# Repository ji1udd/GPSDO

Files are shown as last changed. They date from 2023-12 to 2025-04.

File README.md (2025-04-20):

# GPSDO
## GPSDO for Hermes-Lite2 and a measuring instrument    
[Youtube video](https://youtu.be/AfCz8ohrafM)  

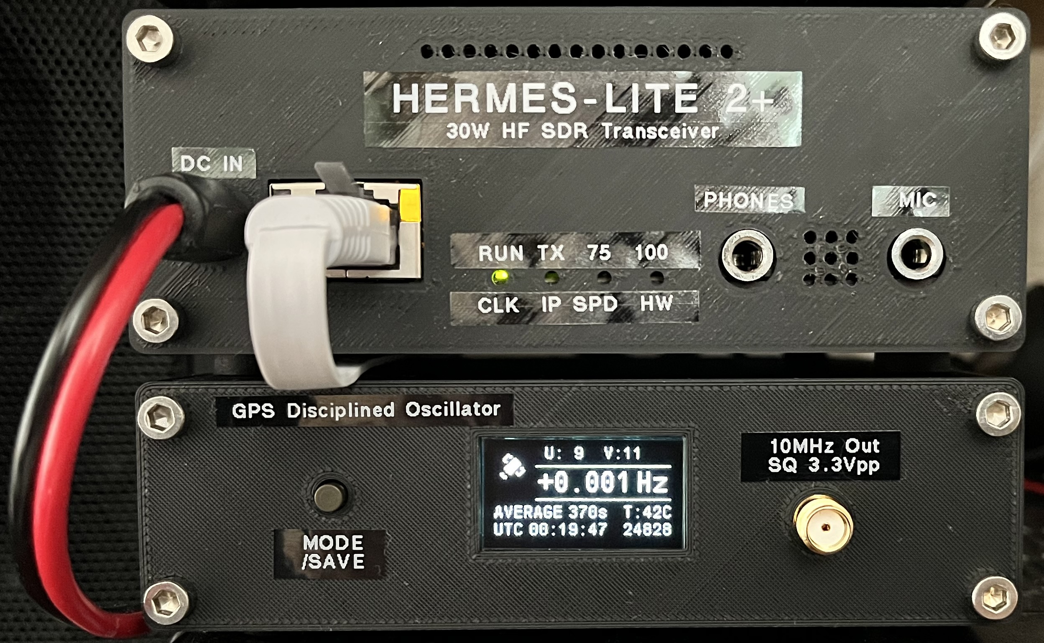
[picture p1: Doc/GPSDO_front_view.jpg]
  

GPSDO using a cheap used OCXO purchased from Aliexpress. It has 10MHz square wave output that can be directly connected to the external clock input of Hermes-Lite2 and 10MHz sine wave output (-10 dBm @ 50 ohm) that can be connected to a measuring instrument such as a spectrum analyzer.

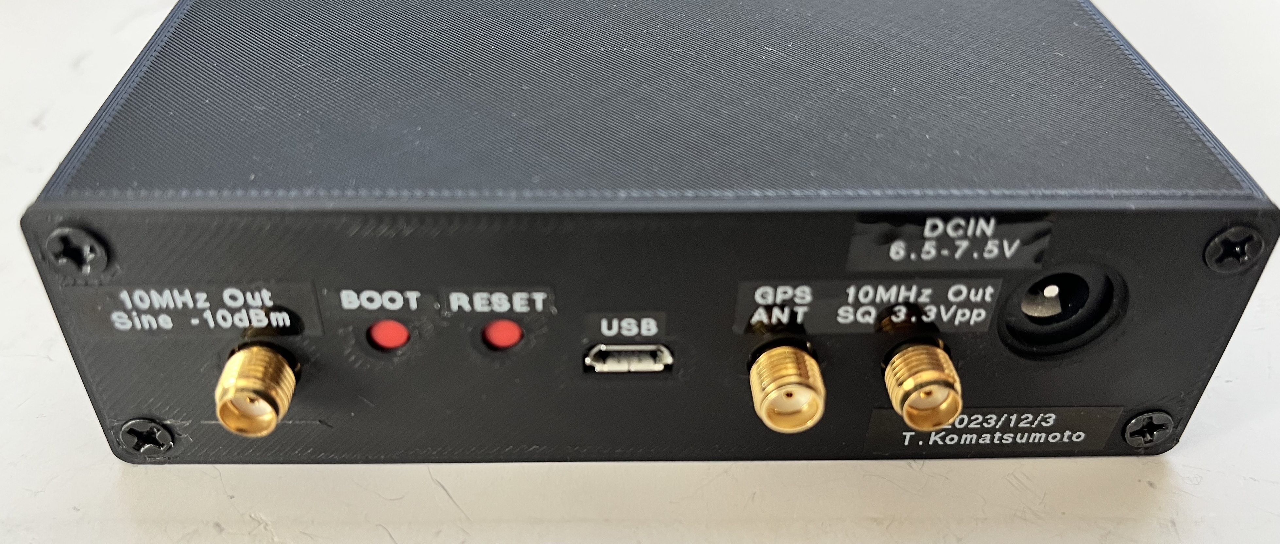
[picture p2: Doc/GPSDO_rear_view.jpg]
  

The 10MHz input SMA connector is located on the back panel of my HL2+. Also, my GPSDO has 10MHz output SMA connector not only on the front panel but also on the back panel. Therefore, these back connectors are connected using a coaxial cable.

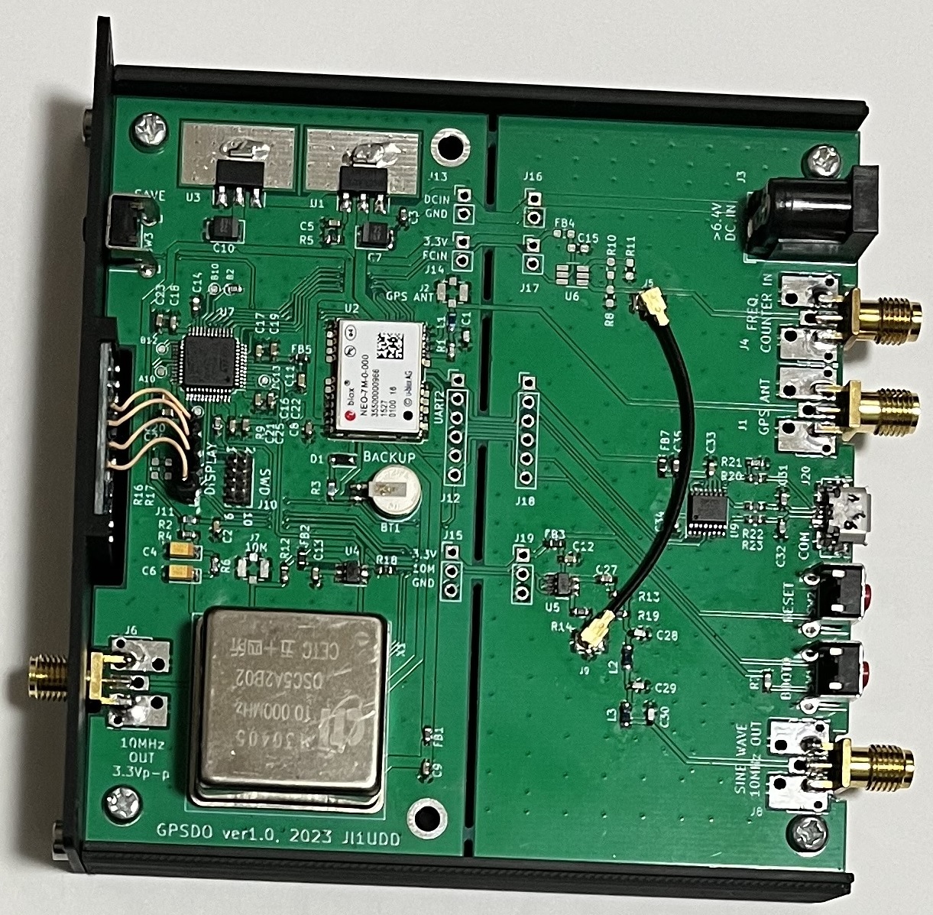
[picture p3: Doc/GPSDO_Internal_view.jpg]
  

## Operation
1. After powering on, wait for the OCXO to warm up to the preset temperature. The default temperature setting is 30 degree C.
2. Next, wait for 1PPS signal from GPS.
3. OCXO frequency control is performed using 1PPS signal. This state is called normal state.
4. During normal state, display mode can be switched by pressing MODE/SAVE button shortly. Display modes are UTC display, frequency integration error display (unit: 0.1Hz) for monitor, latitude and longitude display.
5. During normal state, by pressing MODE/SAVE button longly, the current OCXO temperature minus 5 degree C is saved to STM32 non-volatile memory as the preset temperature. Also the current OCXO control parameter (PWM value) is saved as the initial PWM value. By saving the normal state OCXO temperature and control parameters, it will take less time to stabilize the frequency after cold start. On the other hand, by pressing and holding the MODE/SAVE button while turning on the power, the preset values stored in STM32 non-volatile memory is ignored.

## OLED display
10MHz frequency error and GPSDO status are displayed on the OLED.
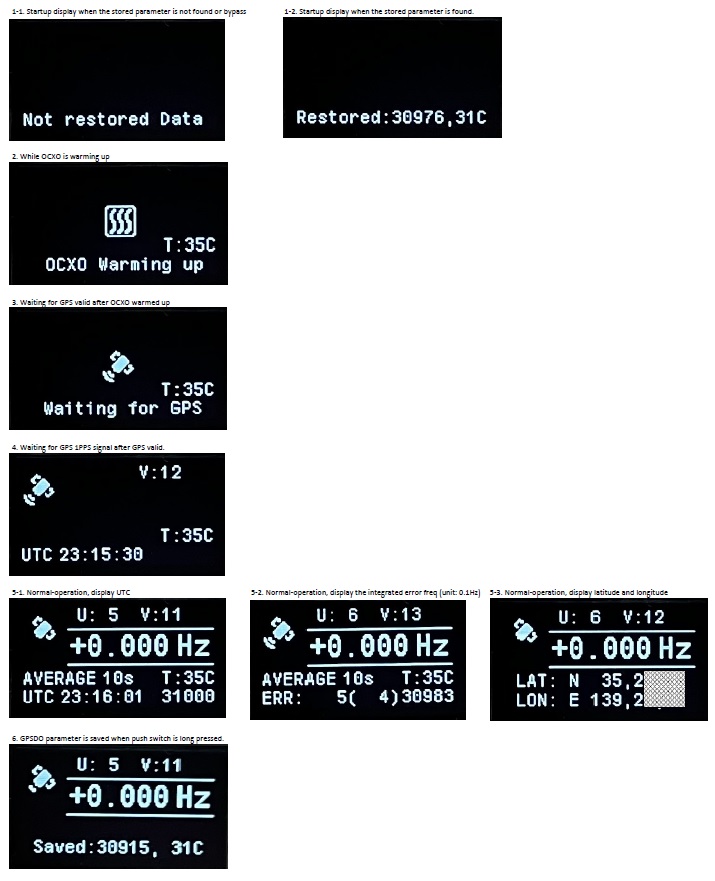
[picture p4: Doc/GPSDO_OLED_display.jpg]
 

## Performance
I checked the accuracy of the frequency of GPSDO output. I made two GPSDOs. Their sine wave outputs are each synchronized to GPS. I input them into my oscilloscope and had them draw a Lissajous curve. Since the Lissajous curve is extremely stable and can take more than 1000 seconds to complete one rotation, I confirmed that the frequency error is on the order of millihertz.  
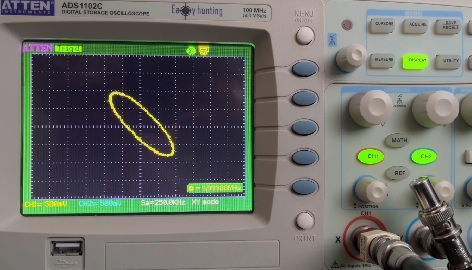
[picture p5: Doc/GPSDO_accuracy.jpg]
 

## STM32 programming
Object files (STM32F410_GPSDO.elf) can be programmed using ST-LINK or USB serial (COM port).

## Enclosure
It's made with 3D printer. The parts of an extender is used for stacking HL2plus over GPSDO. 

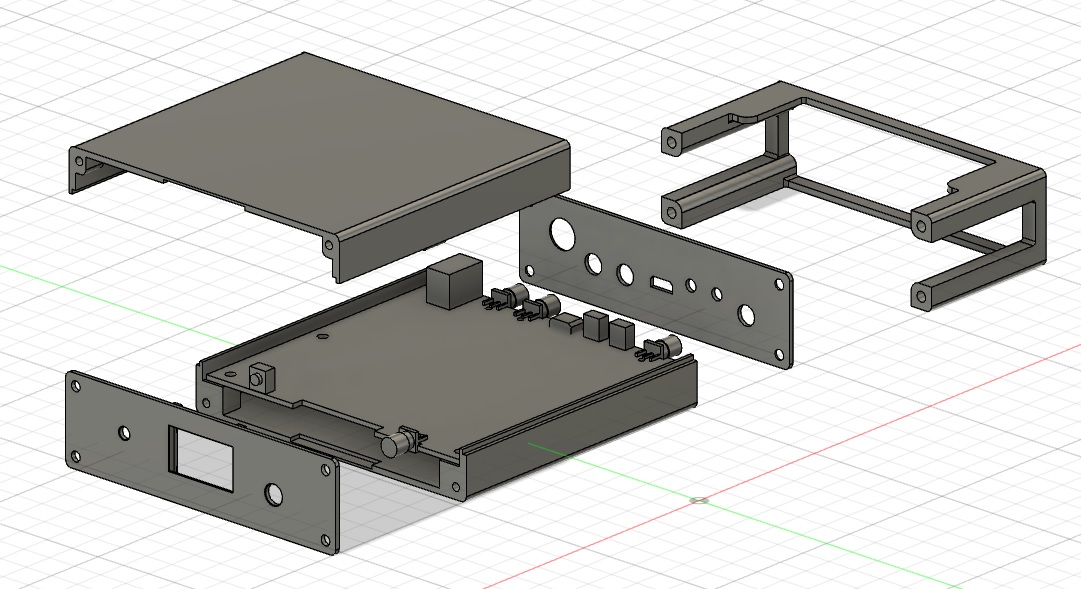
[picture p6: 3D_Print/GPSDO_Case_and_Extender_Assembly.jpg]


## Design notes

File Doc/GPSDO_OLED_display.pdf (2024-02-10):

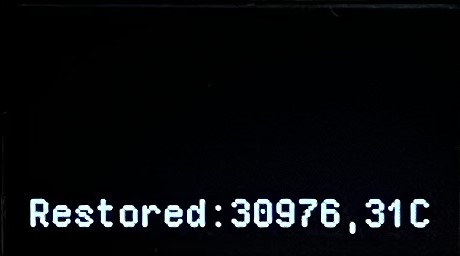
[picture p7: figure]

1-1. Startup display when the stored parameter is not found or bypass | 1-2. Startup display when the stored parameter is found.

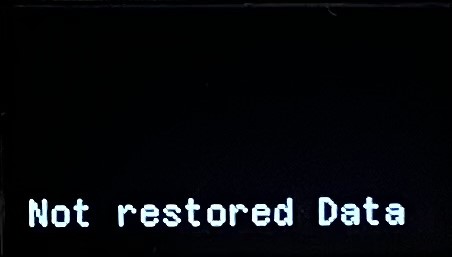
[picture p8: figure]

### 2. While OCXO is warming up

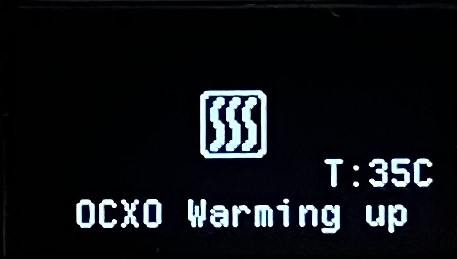
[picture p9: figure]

### 3. Waiting for GPS valid after OCXO warmed up

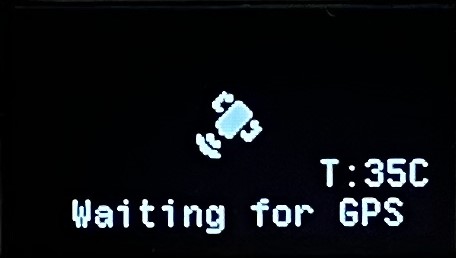
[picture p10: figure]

4. Waiting for GPS 1PPS signal after GPS valid.

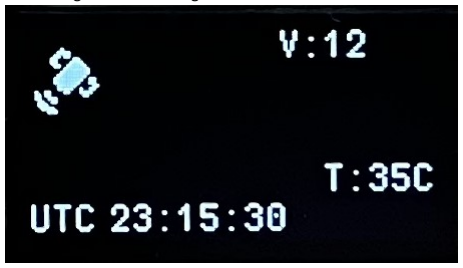
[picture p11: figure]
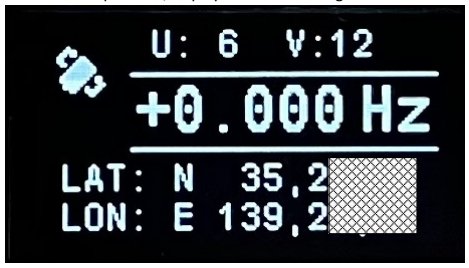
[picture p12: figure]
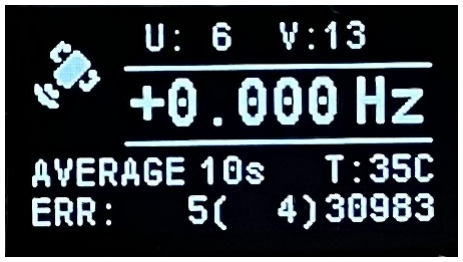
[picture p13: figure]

5-1. Normal-operation, display UTC | 5-2. Normal-operation, display the integrated error freq (unit: 0.1Hz) 5-3. Normal-operation, display latitude and longitude

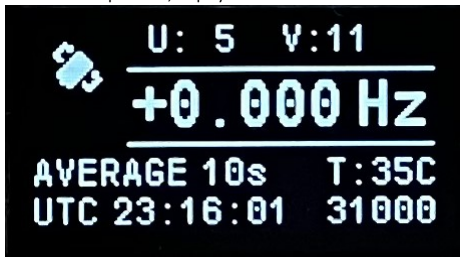
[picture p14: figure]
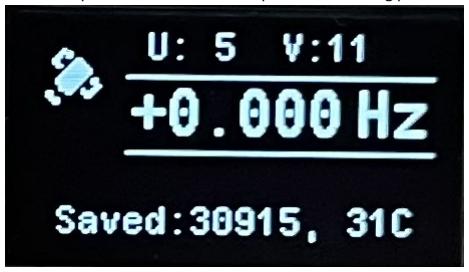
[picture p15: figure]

6. GPSDO parameter is saved when push switch is long pressed.

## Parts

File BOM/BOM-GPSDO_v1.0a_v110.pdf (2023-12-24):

## GPSDO BOM

### Basic Parts

Designator | Qty. | Value/Description | Package | Manufacture | Manufacturer P/N | Supplier | Supplier P/N | Unit Price (USD) | Sub Total (USD)
- | 1 GPS Active Antenna, SMA connector | | - | | | eBay/Aliexpress | | 3 | 3
- | 1 0.96 OLED Display 128x64, SSD1306, I2C | | - | | | eBay/Aliexpress | | 5 | 5
BT1 | 1 Battery MS621F | | - | SII | MS621FE-FL11E | Mouser | 628-MS621FE-FL11E | 1.91 | 1.91
C1 | 1 CAP CER 100pF 50V C0G | | 0603(1608) | Murata | GRM1885C1H101JA01J | | 81-GRM39C101J50J | 0.1 | 0.1
C2, C3, C5, C8, C9,C13, C16, C17, C18, C20, C21, C26 | 12 CAP CER 100nF 50V X7R | | 0603(1608) | Samsung | CL10B104KB8NNNL | Mouser | 187-CL10B104KB8NNNL | 0.009 | 0.108
C11 | 1 CAP CER 10uF 35V X5R 20% | | 0603(1608) | Murata | GRM188R6YA106MA73J | Mouser | 81-GRM188R6YA106MA3J | 0.23 | 0.23
C4, C6 | 2 CAP TANT 10uF 16V 10% | | 3216 | AVX | TAJA106K016RNJ | Mouser | 581-TAJA106K016R | 0.31 | 0.62
C7, C10 | 2 CAP TANT 22uF 16V 20% | | 3528 | AVX | F931C226MBA | Mouser | 647-F931C226MBA | 0.5 | 1
C14 | 1 CAP CER 4.7uF 16V 10% | | 0603(1608) | Samsung | CL10A475KO8NNNC | Mouser | 187-CL10A475KO8NNNC | 0.12 | 0.12
C19, C22, C23, C24, C25, | 5 CAP CER 1uF 25V X5R | | 0603(1608) | Samsung | CL10A105KA8NNNC | Mouser | 187-CL10A105KA8NNNC | 0.1 | 0.5
D1 | 1 Diode PMEG6010CEJ | | SOD-323 | Nexperia | PMEG6010CEJ,115 | Mouser | 771-PMEG6010CEJF | 0.34 | 0.34
FB1, FB2, FB5, FB6 | 4 FB 100MHz 1A.25% | | 0603(1608) | TDK | MPZ1608S601ATA00 | Mouser | 810-MPZ1608S601ATA00 | 0.1 | 0.4
J1, J6 | 2 SMA Connector (GPS ANT, 10MHz OUT) | | SMA(V/H) | | | eBay/Aliexpress | | 1 | 2
J3 | 1 DC POWER JACK | | - | Wurth | 694106301002 | Mouser | 710-694106301002 | 1.02 | 1.02
L1 | 1 IND 56nH 2% | | 0603(1608) | Murata | LQW18AS56NG0ZD | Mouser | 81-LQW18AS56NG0ZD | 0.23 | 0.23
R1 | 1 RES 10 ohm | | 0603(1608) | | | | | 0.1 | 0.1
R2, R3 | 2 RES 1k ohm | | 0603(1608) | | | | | 0.1 | 0.2
R4, R6 | 2 RES 22k ohm | | 0603(1608) | | | | | 0.1 | 0.2
R9, R24 | 2 RES 10k ohm | | 0603(1608) | | | | | 0.1 | 0.2
R5 | 1 RES 0 ohm | | 0603(1608) | | | | | 0.1 | 0.1
R12 | 1 RES 33 ohm | | 0603(1608) | | | | | 0.1 | 0.1
SW3 | 1 Tactile SW Angled | | - | ALPS | SKHHLUA010 | Mouser | 688-SKHHLU | 0.61 | 0.61
U1 | 1 LDO AMS1117 5V 1A | | SOT-223 | Diodes | AZ1117CH-5.0 | Mouser | 621-AZ1117CH-5.0TRG1 | 0.34 | 0.34
U3 | 1 LDO AMS1117 3.3V 1A | | SOT-223 | Diodes | AZ1117CH-3.3 | Mouser | 621-AZ1117CH-3.3TRG1 | 0.38 | 0.38
U2 | 1 GNSS Module NEO 7M | | - | ublox | NEO-7M-0-000 | eBay/Aliexpress | - | 9 | 9
U4 | 1 74LVC2G04 | | SOT-23-6 | TI | SN74LVC2G04DBVR | Mouser | 595-SN74LVC2G04DBVRE | 0.39 | 0.39
U7 | 1 STM32F410CBTx | | LQFP-48 | STMicro | STM32F410CBT6 | Mouser | 511-STM32F410CBT6 | 5.29 | 5.29
U8 | 1 LM73CIMKX-1 | | SOT-23-6 | TI | LM73CIMKX-1/NOPB | Mouser | 926-LM73CIMKX-1/NOPB | 3.04 | 3.04
X1 | 1 OCXO 10MHz | | - | CTI | OSC5A2B02(used) | eBay/Aliexpress | - | 5 | 5
| | | | | | | TOTAL | | 41.528
Designator | Qty. | Value/Description | Package | Manufacture | Manufacturer P/N | Supplier | Supplier P/N | Unit Price (USD) | Sub Total (USD)
J10 | 1 Pin header 1.27mm 5 x 2 pin | | - | Wurth | 62201021121 | Mouser | 710-62201021121 | 1.49 | 1.49
R15 | 1 RES 100 ohm | | 0603(1608) | | | | | 0.1 | 0.1
| | | | | | | TOTAL (include Basic parts) | | 43.118
Designator | Qty. | Value/Description | Package | Manufacture | Manufacturer P/N | Supplier | Supplier P/N | Unit Price (USD) | Sub Total (USD)
C31, C32 | 2 CAP CER 47pF 50V C0G | | 0603(1608) | | | | | 0.1 | 0.2
C33, C34 | 2 CAP CER 100nF 50V X7R | | 0603(1608) | Samsung | CL10B104KB8NNNL | Mouser | 187-CL10B104KB8NNNL | 0.009 | 0.018
C35 | 1 CAP CER 10uF 35V X5R | | 0603(1608) | Murata | GRM188R6YA106MA73J | Mouser | 81-GRM188R6YA106MA3J | 0.23 | 0.23
FB7 | 1 FB 100MHz 1A.25% | | 0603(1608) | TDK | MPZ1608S601ATA00 | Mouser | 810-MPZ1608S601ATA00 | 0.1 | 0.1

### Option Parts (in case of using ST-LINK for STM32 programming)

### Option Parts (in case of using UART for STM32 programming)

R7 | 1 RES 1k ohm | 0603(1608) | | | | | 0.1 | 0.1
R22, R23 | 2 RES 27 ohm | 0603(1608) | | | | | 0.1 | 0.2
R20 | 1 RES 4.7k ohm | 0603(1608) | | | | | 0.1 | 0.1
R21 | 1 RES 10k ohm | 0603(1608) | | | | | 0.1 | 0.1
J20 | 1 USB Micro-B | - | Hirose | ZX62R-B-5P | Mouser | 798-ZX62R-B-5P30 | 1.02 | 1.02
SW1, SW2 | 2 Tactile SW Angled | - | ALPS | SKHHLUA010 | Mouser | 688-SKHHLU | 0.61 | 1.22
U9 | 1 FT230XS | SSOP-16 | FTDI | FT230XS-R | Mouser | 895-FT230XS-R | 2.26 | 2.26
| | | | | | TOTAL (include Basic parts) | | 47.076
Designator | Qty. | Value/Description | Package | Manufacture | Manufacturer P/N | Supplier | Supplier P/N | Unit Price (USD) | Sub Total (USD)
C12, C27 | 2 CAP CER 100nF 50V X7R | 0603(1608) | Samsung | CL10B104KB8NNNL | Mouser | 187-CL10B104KB8NNNL | 0.009 | 0.018
C28, C30 | 2 CAP CER 330pF 50V C0G | 0603(1608) | | | | | 0.1 | 0.2
C29 | 1 CAP CER 680pF 50V C0G | 0603(1608) | | | | | 0.1 | 0.1
FB3 | 1 FB 100MHz 1A.25% | 0603(1608) | TDK | MPZ1608S601ATA00 | Mouser | 810-MPZ1608S601ATA00 | 0.1 | 0.1
J8 | 1 SMA Connector (10MHz OUT) | SMA(V/H) | | | eBay/Aliexpress | | 1 | 1
L2, L3 | 2 IND 820nH 5% | 0805(2012) | Murata | LQW21HNR82J00L | Mouser | 81-LQW21HNR82J00L | 0.37 | 0.74
R18 | 1 RES 0 ohm | 0603(1608) | | | | | 0.1 | 0.1
R13 | 1 RES 470 ohm | 0603(1608) | | | | | 0.1 | 0.1
R19 | 1 RES 49.9 ohm | 0603(1608) | | | | | 0.1 | 0.1
U5 | 1 74LVC2G04 | SOT-23-6 | TI | SN74LVC2G04DBVR | Mouser | 595-SN74LVC2G04DBVRE | 0.39 | 0.39
J4 | 1 SMA Connector (10MHz OUT) | SMA(V/H) | eBay/Aliexpress | | 1 | 1
J5, J9 | 2 uFL Connector (10MHz interconnect) | UFL | eBay/Aliexpress | | 0.5 | 1
R14 | 1 RES 33 ohm | 0603(1608) | | | 0.1 | 0.1
- | 1 uFL Coaxial cable L=50mm | | eBay/Aliexpress | | 1 | 1
| | | | TOTAL | | 5.948
C15,FB4, R8, R10, R11, U6 | errata
J2 | uFL Connector (exclusive with J1)
J7 | uFL Connector (exclusive with J6)
R16, R17 | I2C pull-up

### Not assemble parts

### Option Parts (Additional 10MHz Outputs)

(One more squar wave Output)

(Sine Wave Output)

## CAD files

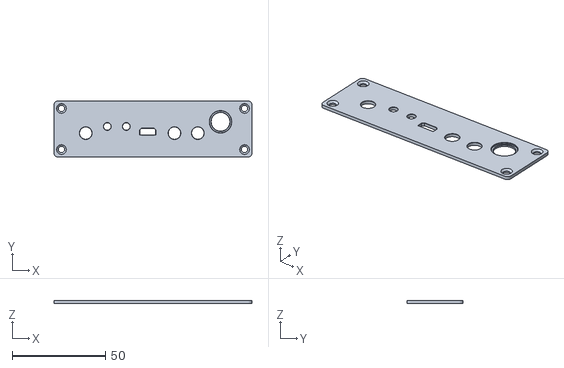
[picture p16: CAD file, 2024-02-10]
3D_Print/GPS_BackPanel v9.stl
106.0 x 30.0 x 1.50

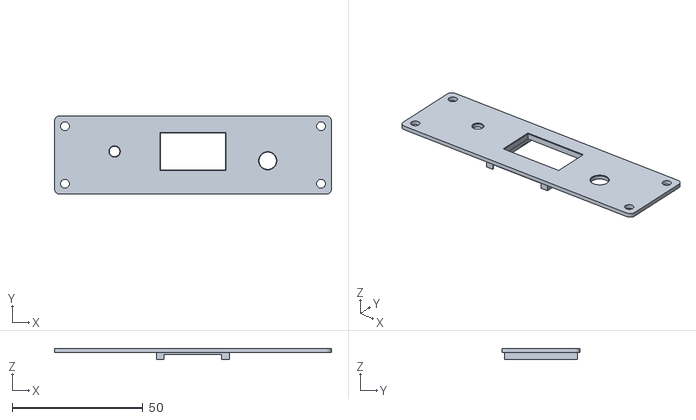
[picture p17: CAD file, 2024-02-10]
3D_Print/GPS_FrontPanel v2.stl
106.0 x 30.0 x 4.30

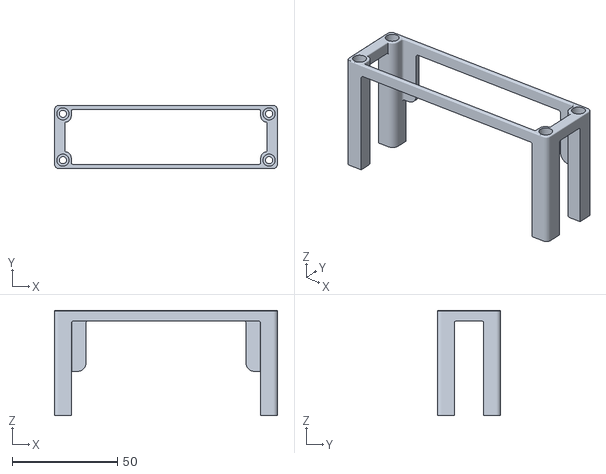
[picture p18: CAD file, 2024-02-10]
3D_Print/GPS_BP_Extender v3.stl
106.0 x 30.0 x 50.0

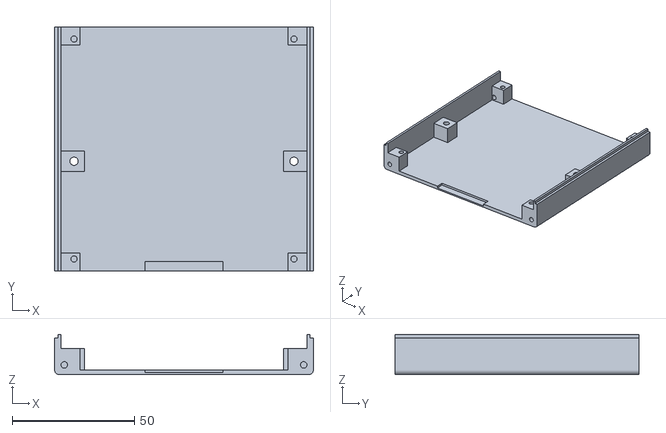
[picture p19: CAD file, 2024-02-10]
3D_Print/GPS_Bottom v14.stl
106.0 x 100.0 x 16.5

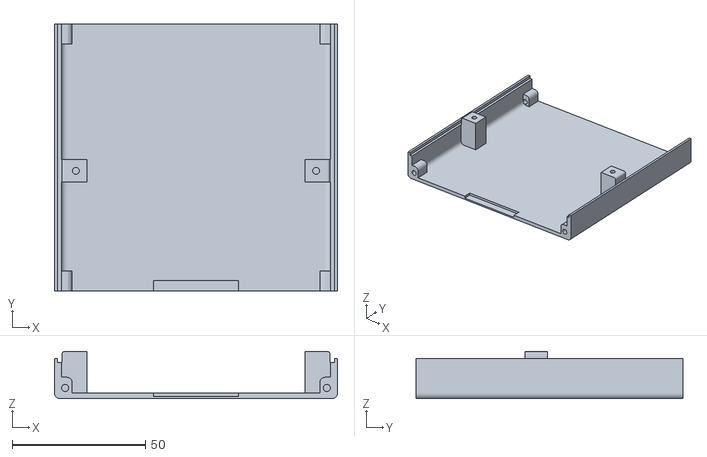
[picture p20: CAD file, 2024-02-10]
3D_Print/GPS_Top v8.stl
106.0 x 100.0 x 17.6

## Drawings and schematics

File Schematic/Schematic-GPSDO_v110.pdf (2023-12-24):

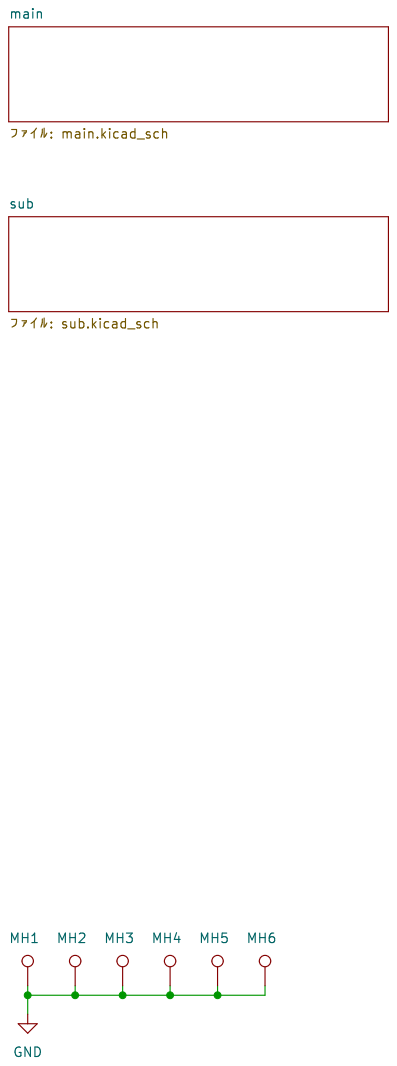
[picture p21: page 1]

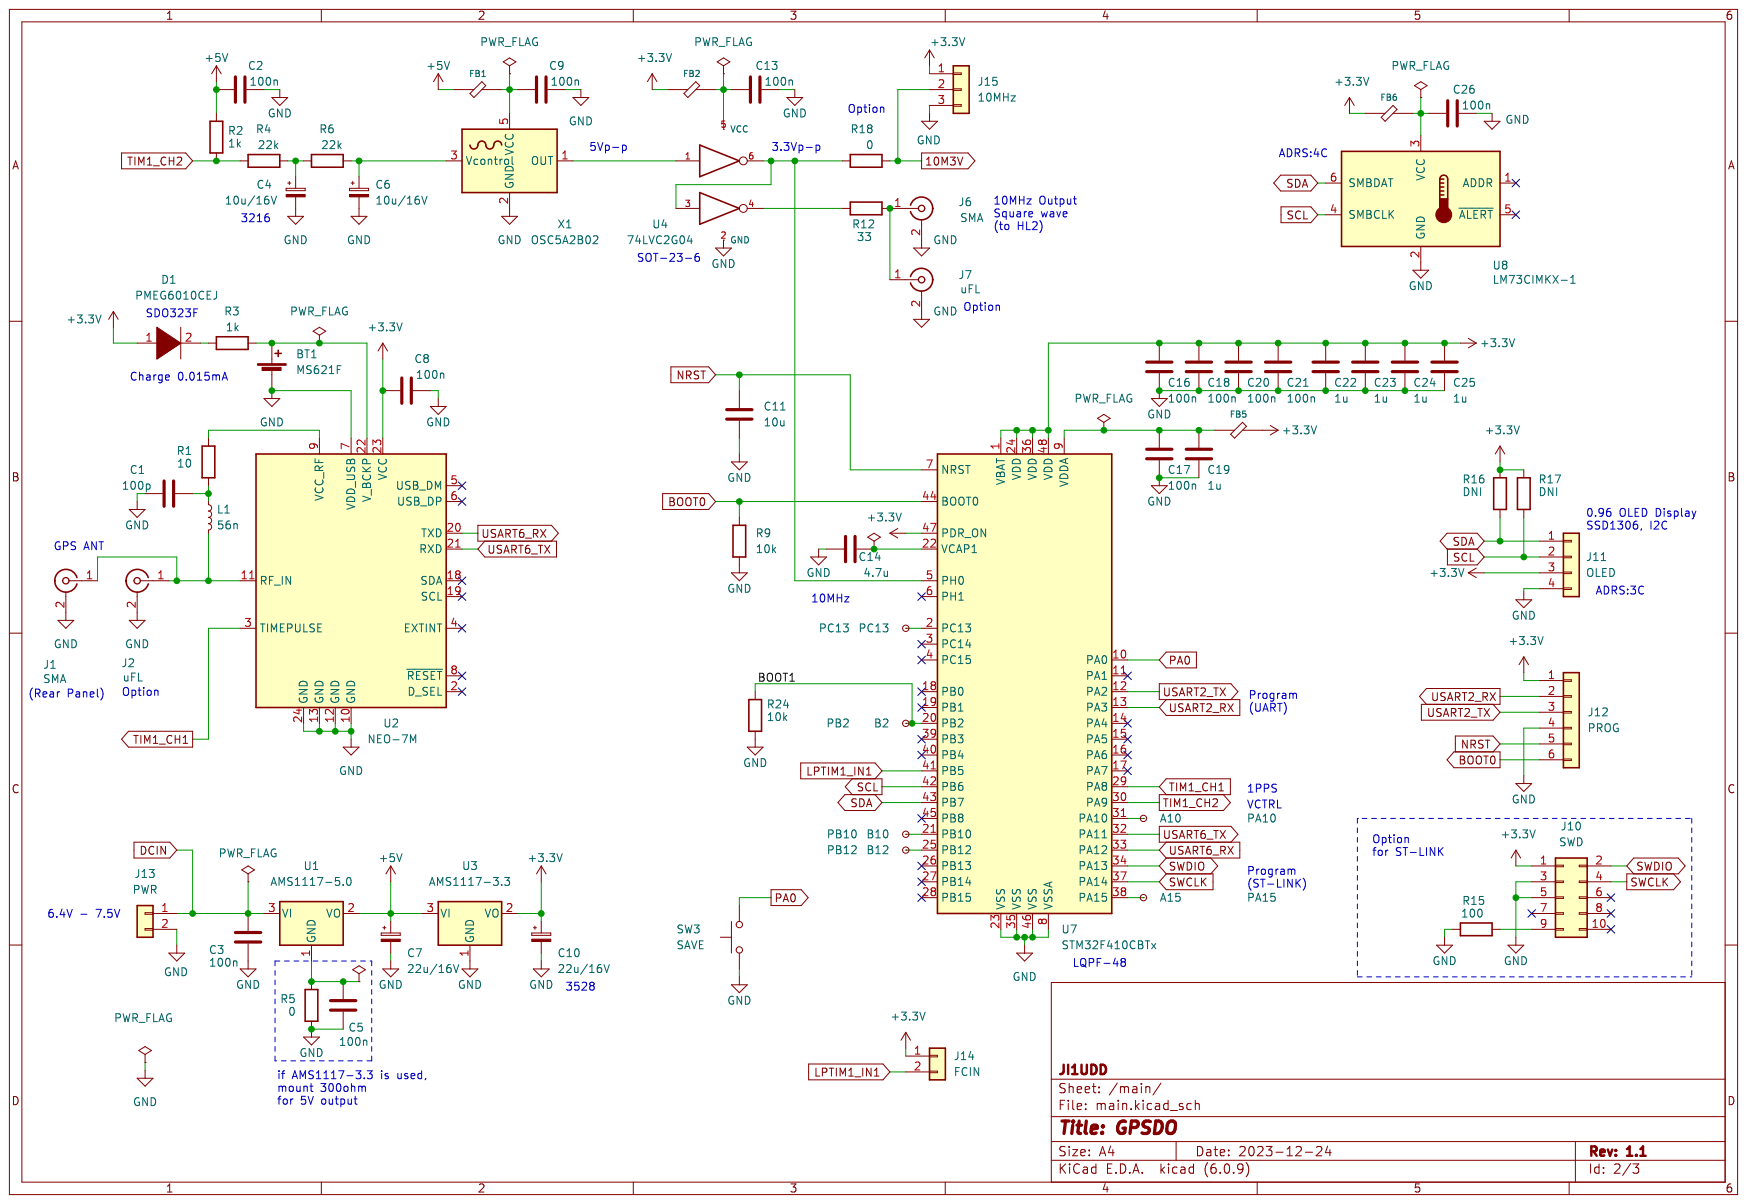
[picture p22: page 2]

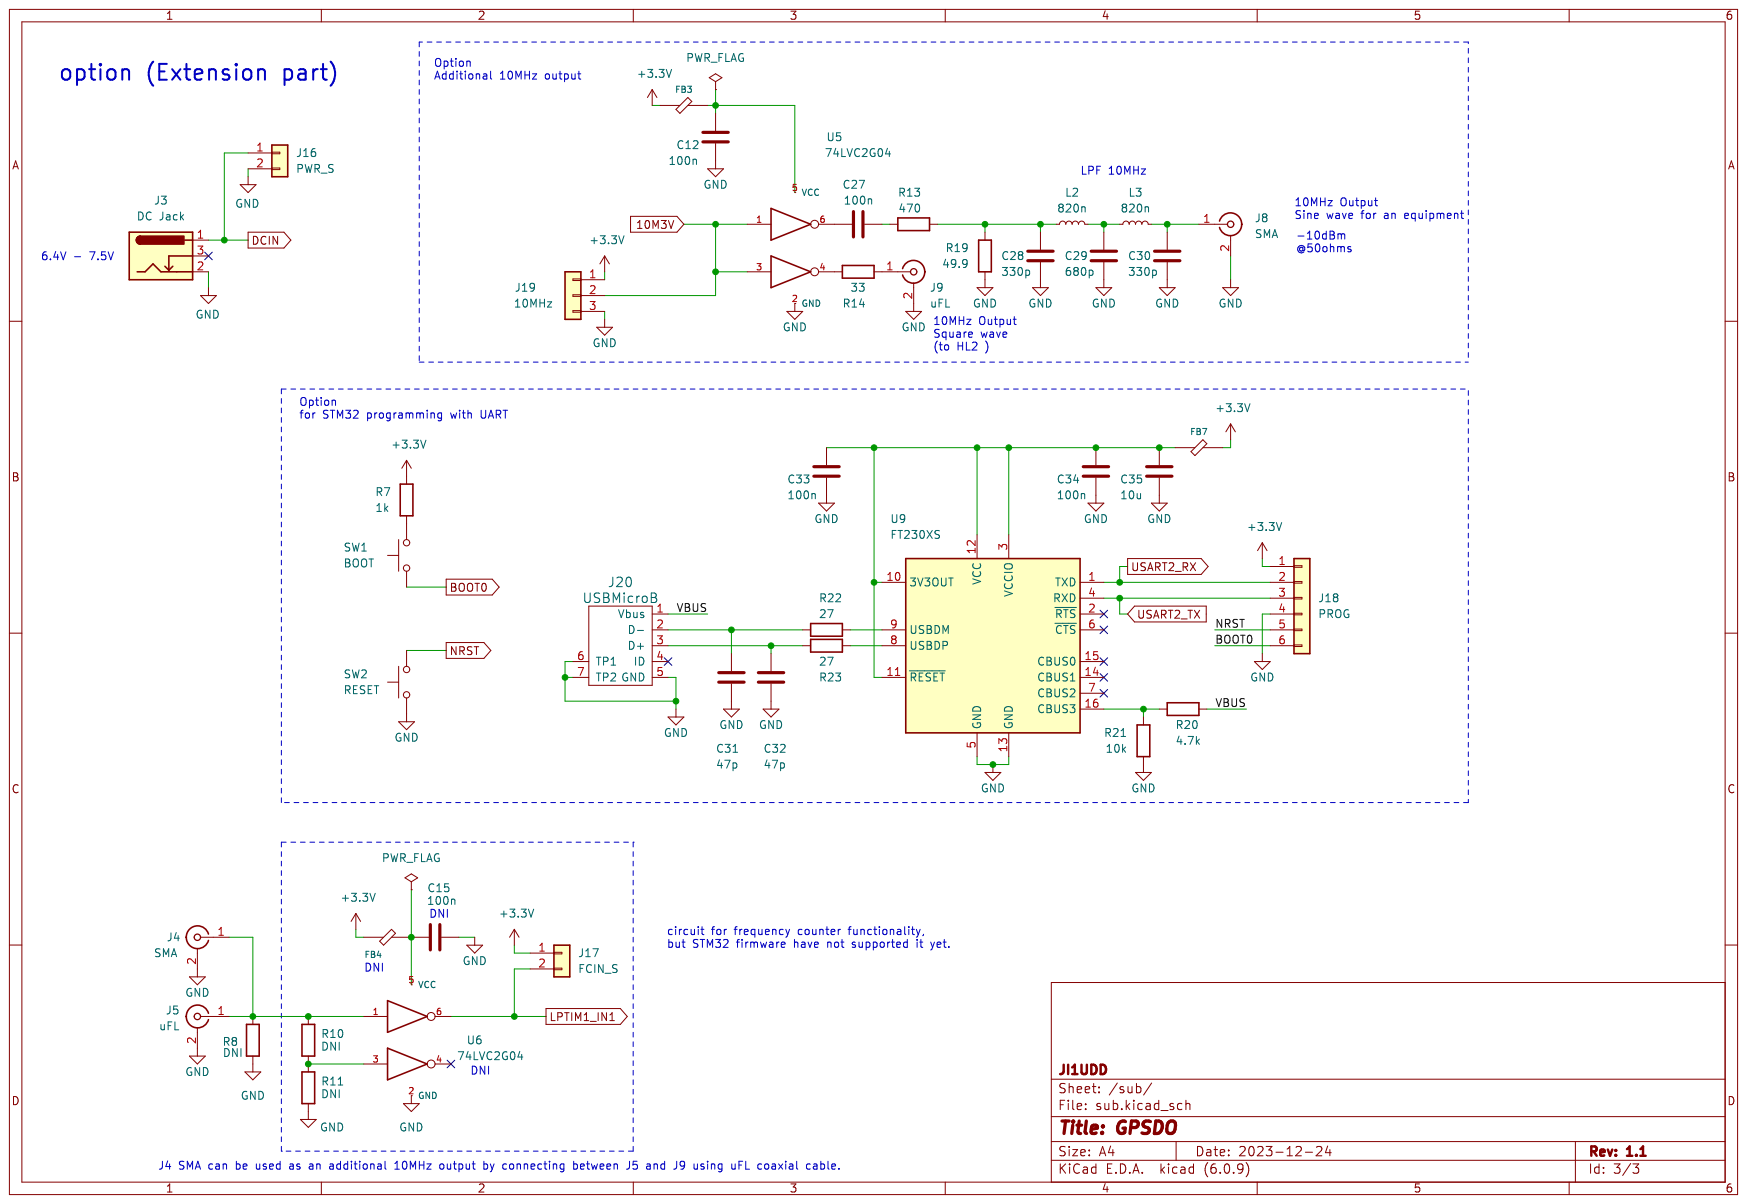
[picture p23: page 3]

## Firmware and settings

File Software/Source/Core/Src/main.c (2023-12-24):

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
/* Includes ------------------------------------------------------------------*/
#include "main.h"

/* USER CODE BEGIN Includes */
#include <stdbool.h>
#include <stdio.h>
#include <stdlib.h>
#include <string.h>
#include "ssd1306.h"
#include "fonts.h"
#include "ocxo.h"
#include "gps.h"
#include "display.h"

/* USER CODE END Includes */

/* USER CODE BEGIN PTD */
// STM32F410CBT6:Flash 128KB -> last sector 4 (64KB area)
#define FLASH_DATA_SECTOR		FLASH_SECTOR_4
#define FLASH_DATA_ADR			0x08010000
#define FLASH_DATA_SECTORSIZE	0x10000

#define LM73_I2C_ADDR       	0x98
#define OCXO_DEF_THRESHOLD		30		// degree C
#define SW_PRESSED				0
#define SW_SHORT_THRESHOLD  	3		// (Unit:10ms) 30msec
#define SW_LONG_THRESHOLD   	300		// (Unit:10ms) 3000msec

#define STATE_INIT_NOT_RESTORED	0
#define STATE_INIT_RESTORED		1
#define STATE_WAIT_WARMUP		2
#define STATE_WAIT_TIMEVALID	3
#define STATE_WAIT_GPSVALID		4
#define STATE_GPSVALID			5

/* USER CODE END PTD */

I2C_HandleTypeDef hi2c1;

TIM_HandleTypeDef htim1;
TIM_HandleTypeDef htim11;

UART_HandleTypeDef huart2;
UART_HandleTypeDef huart6;
DMA_HandleTypeDef hdma_usart6_rx;
DMA_HandleTypeDef hdma_usart6_tx;

/* USER CODE BEGIN PV */
int32_t	tim1_ovf_cnt = 0;
int32_t	cnt_1pps;
bool	previous_cnt_valid = false;
bool	update_cnt_1pps = false;
int32_t	tim11_ovf_cnt = 0;
int32_t	KeyStatus = 0;

/* USER CODE END PV */

void SystemClock_Config(void);
static void MX_GPIO_Init(void);
static void MX_DMA_Init(void);
static void MX_I2C1_Init(void);
static void MX_TIM1_Init(void);
static void MX_USART6_UART_Init(void);
static void MX_TIM11_Init(void);
static void MX_USART2_UART_Init(void);
/* USER CODE BEGIN 0 */
// LM73(I2C) Read out TCXO temperature (signed 10 bit)
int32_t LM73_temperature(void){
  uint8_t buf[2];
  HAL_I2C_Master_Receive(&hi2c1, LM73_I2C_ADDR, buf, 2, 10);
  return ((buf[0] << 1) | (buf[1] >> 7));
}

int32_t LoadData32Flash(uint32_t *data1, uint32_t *data2) {
  uint32_t* adr = (uint32_t *)(FLASH_DATA_ADR + FLASH_DATA_SECTORSIZE) - 2;
  for( int i=0; i < FLASH_DATA_SECTORSIZE/4/2; i++ ) {	// search from end of sector
    if ( *adr != 0xFFFFFFFF) {							// if not blank (data exist)
      *data1 = *adr++;
      *data2 = *adr;
      return 0;
    }
    adr -= 2;
  }
  return -1;
}

void SaveData32Flash(uint32_t data1, uint32_t data2) {
  HAL_FLASH_Unlock();

  uint32_t* adr = (uint32_t *)(FLASH_DATA_ADR + FLASH_DATA_SECTORSIZE) - 1;
  if (*adr != 0xFFFFFFFF ) {		// if not spire
    FLASH_EraseInitTypeDef erase;
    erase.TypeErase = FLASH_TYPEERASE_SECTORS;
    erase.Sector = FLASH_DATA_SECTOR;	// STM32F410CBT6 FLASH_SECTOR_4
    erase.NbSectors = 1;
    erase.VoltageRange = FLASH_VOLTAGE_RANGE_3;
    uint32_t r; 					// SectorError
    HAL_FLASHEx_Erase(&erase, &r);
  }

  adr = (uint32_t *)FLASH_DATA_ADR;
  for (int i=0; i < FLASH_DATA_SECTORSIZE/4/2; i++) { // search from top of sector
    if (*adr == 0xFFFFFFFF) {                  // if blank
      HAL_FLASH_Program(FLASH_TYPEPROGRAM_WORD, (uint32_t)adr++, data1);
      HAL_FLASH_Program(FLASH_TYPEPROGRAM_WORD, (uint32_t)adr, data2);
      break;
    }
    adr += 2;
  }
  HAL_FLASH_Lock();
}

bool IsPushSWPressed(void) {
  return (HAL_GPIO_ReadPin(PushSW_GPIO_Port, PushSW_Pin) == SW_PRESSED);
}

int32_t CheckPushSW(void) {
  static int32_t cnt = 0;
  static bool	 detect_push_long = false;

  if (IsPushSWPressed()) {
    if (cnt > SW_LONG_THRESHOLD -1 ) {
   	  if (detect_push_long) {
   		return 0;
   	  } else {
     	detect_push_long = true;
     	return 2;
   	  }
    } else {
      cnt++;
      return 0;
    }
  } else {
	if ((detect_push_long == false) && (cnt > SW_SHORT_THRESHOLD - 1)) {
      cnt = 0;
      return 1;
	} else {
	  detect_push_long = false;
	  cnt = 0;
	  return 0;
	}
  }
}

/* USER CODE END 0 */

/**
  * @brief  The application entry point.
  * @retval int
  */
int main(void)
{
  /* USER CODE BEGIN 1 */
  bool ocxo_warm_up = false;
  bool gps_valid = false;
  bool gps_time_valid = false;
  bool req_update_state = false;
  bool req_update_display = false;
//bool req_display_location = false;
  bool req_display_msg_save = false;
  int32_t state;
  int32_t next_state;
  int32_t state_delay = 0;
  int32_t disp_mode = 0;
  int32_t disp_hold_cnt = 0;
  int32_t icon_sig_pat;
  int32_t temperature;
  int32_t saved_temperature;
  int32_t ocxo_threshold = OCXO_DEF_THRESHOLD;
  int32_t r;
  uint32_t k1, k2;

  /* USER CODE END 1 */

  /* MCU Configuration--------------------------------------------------------*/

  /* Reset of all peripherals, Initializes the Flash interface and the Systick. */
  HAL_Init();

  /* Configure the system clock */
  SystemClock_Config();

  /* Initialize all configured peripherals */
  MX_GPIO_Init();
  MX_DMA_Init();
  MX_I2C1_Init();
  MX_TIM1_Init();
  MX_USART6_UART_Init();
  MX_TIM11_Init();
  MX_USART2_UART_Init();
  /* USER CODE BEGIN 2 */
  uart6_init();

  if (ssd1306_Init(&hi2c1) != 0) {
    Error_Handler();
  }
  HAL_Delay(1000);

  // load saved parameter
  if (!IsPushSWPressed()) {
	r = LoadData32Flash(&k1, &k2);
	if (r == -1) {
	  state = next_state = STATE_INIT_NOT_RESTORED;
	} else {
	  set_control_pwm_data((int32_t) k1);
	  ocxo_threshold = k2;
      state = next_state = STATE_INIT_RESTORED;
    }
  } else {
	state = next_state = STATE_INIT_NOT_RESTORED;
  }

  // Start Timer
  HAL_TIM_Base_Start_IT(&htim11);	// Timer11
  ocxo_init();						// Timer1

  /* USER CODE END 2 */

  /* Infinite loop */
  /* USER CODE BEGIN WHILE */
  while (1)
  {
    /* USER CODE END WHILE */

    /* USER CODE BEGIN 3 */
//	HAL_GPIO_WritePin(LED1_GPIO_Port, LED1_Pin, GPIO_PIN_SET);// for debug

    // OCXO frequency control
	//   the interval depends on 1PPS generated by GPS module
	if (state > STATE_WAIT_WARMUP) {
	  ocxo_control();
	}

    // PushSW operation
 	r = KeyStatus;			// read and clear KeyStatus
  	KeyStatus = 0;
	if (state == STATE_GPSVALID) {
  	  if (r == 1) {			// short pressed?
  		disp_mode++;
  		if (disp_mode > 2) disp_mode = 0;
  	  }
  	  else if (r == 2) {	// long pressed?
  	    r = get_control_pwm_data();
  	    saved_temperature = temperature - 5;
  	    SaveData32Flash((uint32_t) r, (uint32_t) saved_temperature);
  	    req_display_msg_save = true;
	  }
	}

	// Receive GPS message ( measured time max. 150us)
//	HAL_GPIO_WritePin(LED2_GPIO_Port, LED2_Pin, GPIO_PIN_SET);
	uart6_err_ckcl();
	while (get_gps_msg() == true) {
	  // Output NMEA sentence using UART2 (USB serial) for debugging
//    HAL_UART_Transmit(&huart2, (const uint8_t *)gps_msg, strlen((const char *)gps_msg), 10);
	  r = msg_parse(gps_msg);
	  if (r > 0) {  // if received GPRMC message
	    gps_valid = (r & 4)? true : false;
		gps_time_valid = (r & 2)? true : false;
		tim11_ovf_cnt = 0;
		req_update_state = true;
	  }
	}
//	HAL_GPIO_WritePin(LED2_GPIO_Port, LED2_Pin, GPIO_PIN_RESET);

	// if GPRMC sentence is not detected, update state/display every 1.2sec
	if (tim11_ovf_cnt > 120) {
		tim11_ovf_cnt = 0;
		req_update_state = true;
	}

    // update state basically every 1sec
	if (req_update_state) {
	  req_update_state = false;

	  // Measure OCXO temperature
	  temperature = LM73_temperature();
	  if (temperature > ocxo_threshold)
	    ocxo_warm_up = true;

	  // state machine
	  if (state_delay == 0) {
		state = next_state;
		req_update_display = true;
		switch(state) {
		  case STATE_INIT_NOT_RESTORED:
		  case STATE_INIT_RESTORED:
		    next_state = STATE_WAIT_WARMUP;
		    state_delay = 3; // 3sec
		    break;

		  case STATE_WAIT_WARMUP:
		    if (ocxo_warm_up) next_state = STATE_WAIT_TIMEVALID;
		    break;

		  case STATE_WAIT_TIMEVALID:
		    if (gps_time_valid) next_state = STATE_WAIT_GPSVALID;
		    break;

		  case STATE_WAIT_GPSVALID:
		    if (gps_valid) next_state = STATE_GPSVALID;
		    else if (!gps_time_valid) next_state = STATE_WAIT_TIMEVALID;
		    break;

		  case STATE_GPSVALID:
		    if (!gps_valid) next_state = STATE_WAIT_GPSVALID;
		    else if (!gps_time_valid) next_state = STATE_WAIT_TIMEVALID;
		    break;

		  default:
		    next_state = STATE_WAIT_WARMUP;
		    break;
		}

	  } else {
		state_delay--;
	  }
	} // if(req_update_state)

	// display control
    if (disp_hold_cnt) {
      disp_hold_cnt--;
    }
    else if (req_update_display) {
      req_update_display = false;
	  switch(state) {
		case STATE_INIT_NOT_RESTORED:
	      ssd1306_Fill(Black);
	      display_msg_not_load();
	      disp_hold_cnt = 3;
		  break;

		case STATE_INIT_RESTORED:
		  ssd1306_Fill(Black);
		  display_msg_restore(get_control_pwm_data(), ocxo_threshold);
		  disp_hold_cnt = 3;
		  break;

		case STATE_WAIT_WARMUP:
		  ssd1306_Fill(Black);
		  display_heater_icon(IPOS_Center_X, IPOS_Center_Y);
		  display_msg_warming_up();
		  display_temperature(temperature);
		  break;

		case STATE_WAIT_TIMEVALID:
		  ssd1306_Fill(Black);
		  display_satellite_icon(IPOS_Center_X, IPOS_Center_Y);
		  display_msg_waiting_gps();
		  display_temperature(temperature);
		  break;

		case STATE_WAIT_GPSVALID:
		  ssd1306_Fill(Black);
		  display_satellite_icon(IPOS_Corner_X, IPOS_Corner_Y);
		  display_temperature(temperature);
		  display_time();
		  display_SatellitesInView();
		  icon_sig_pat = 0;
		  break;

		case STATE_GPSVALID:
		  display_sat_icon_sig(IPOS_Corner_X, IPOS_Corner_Y, icon_sig_pat++);
		  if (icon_sig_pat > 2) icon_sig_pat = 0;
		  display_SatellitesUsed();
		  display_SatellitesInView();
		  display_freq_error();
		  display_blank_row(TPOS_Y3, Font_7x10);
		  display_blank_row(TPOS_Y4, Font_7x10);
		  if (req_display_msg_save) {
			  req_display_msg_save = false;
			  display_msg_save(get_control_pwm_data(), saved_temperature);
			  disp_hold_cnt = 5;
		  } else {
			switch(disp_mode) {
			  case 0:
		        display_control_period();
			    display_temperature(temperature);
		        display_time();
			    display_pwm_data();
			    break;
			  case 1:
		        display_control_period();
			    display_temperature(temperature);
			    display_summing_error();
			    display_pwm_data();
			    break;
			  case 2:
                display_Latitude();
                display_Longitude();
                break;
			  default:
				break;
			} // switch(disp_mode)
		  } // else
		  break;

		default:
		  break;
	  } // switch
	  ssd1306_UpdateScreen(&hi2c1);	// execution time: 100ms
	} // if (req_update_display)

//  HAL_GPIO_WritePin(LED1_GPIO_Port, LED1_Pin, GPIO_PIN_RESET);
  } // while
  /* USER CODE END 3 */
}

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
/* USER CODE BEGIN 4 */
void HAL_TIM_IC_CaptureCallback(TIM_HandleTypeDef *htim){
// static bool  previous_cnt_valid = false;
 static int32_t previous_cnt;

 if(htim == &htim1){
  int32_t tmp = tim1_ovf_cnt;
  tim1_ovf_cnt = 0;          		// clear overflow counter
  int32_t cnt = TIM1-> CCR1; 		// get cnt(16bit) and clear capture interrupt flag

  if (previous_cnt_valid) {			// previous cnt value exists?
   cnt_1pps = (tmp * 65536) + cnt - previous_cnt;     // Yes, calculate whole pulse in 1PSS
   previous_cnt = cnt; 				// store cnt value into previous_count for next calculation
   update_cnt_1pps = true;			// set 1pps cnt update flag
  }
  else {
   previous_cnt = cnt;				// store cnt value into previous_count
   previous_cnt_valid = true;		// set previous count flag
  }
 }
}

void HAL_TIM_PeriodElapsedCallback(TIM_HandleTypeDef *htim) {
 if(htim == &htim1){				// Timer1
  TIM1-> SR &= 0x1EFE;				// clear update interrupt flag
  tim1_ovf_cnt++;					// increment overflow count
 }
 else if(htim == &htim11){			// Timer11
  TIM11-> SR &= 0x1EFE;				// clear update interrupt flag
  tim11_ovf_cnt++;					// increment overflow count
  if (KeyStatus == 0) {				// Check PushSW
    KeyStatus = CheckPushSW();
  }
 }
}

/* USER CODE END 4 */
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


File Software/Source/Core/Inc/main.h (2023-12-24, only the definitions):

#define LED1_Pin GPIO_PIN_13
#define LED1_GPIO_Port GPIOC
#define PushSW_Pin GPIO_PIN_0
#define PushSW_GPIO_Port GPIOA
#define LED2_Pin GPIO_PIN_10
#define LED2_GPIO_Port GPIOB
#define TIM1_CH1_IC_Pin GPIO_PIN_8
#define TIM1_CH1_IC_GPIO_Port GPIOA
#define TIM1_CH2_PWM_Pin GPIO_PIN_9
#define TIM1_CH2_PWM_GPIO_Port GPIOA

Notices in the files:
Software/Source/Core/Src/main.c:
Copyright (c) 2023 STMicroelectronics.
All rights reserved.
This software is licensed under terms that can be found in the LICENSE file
